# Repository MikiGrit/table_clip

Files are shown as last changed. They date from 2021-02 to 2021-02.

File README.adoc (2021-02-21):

= Modular TableClip System

Do you have table so cluttered you don't see the color of the desk? TableClip to the rescue! ;)

Jokes aside, some time ago I've got inspired by the https://www.thingiverse.com/thing:2892387[USB Cable Organizer] and thought that this could be extended to other useful things and also improved.

So I designed modular system that is divided to parts. The table clip itsef and various modules that can be attached to the clip through lock mechanism.

.Available modules
* cable holder
* pen and paper holder
* headphones holder
* storage box

For the ready-to-print `stl` files, go to https://www.prusaprinters.org/prints/57023-modular-tableclip-system-with-sources[TableClip on prusaprinters.org]

*BUT* the best thing about it is that I'm sharing the sources here. So everybody can design his own modules that can be attached to the base module.

== Designing own modules

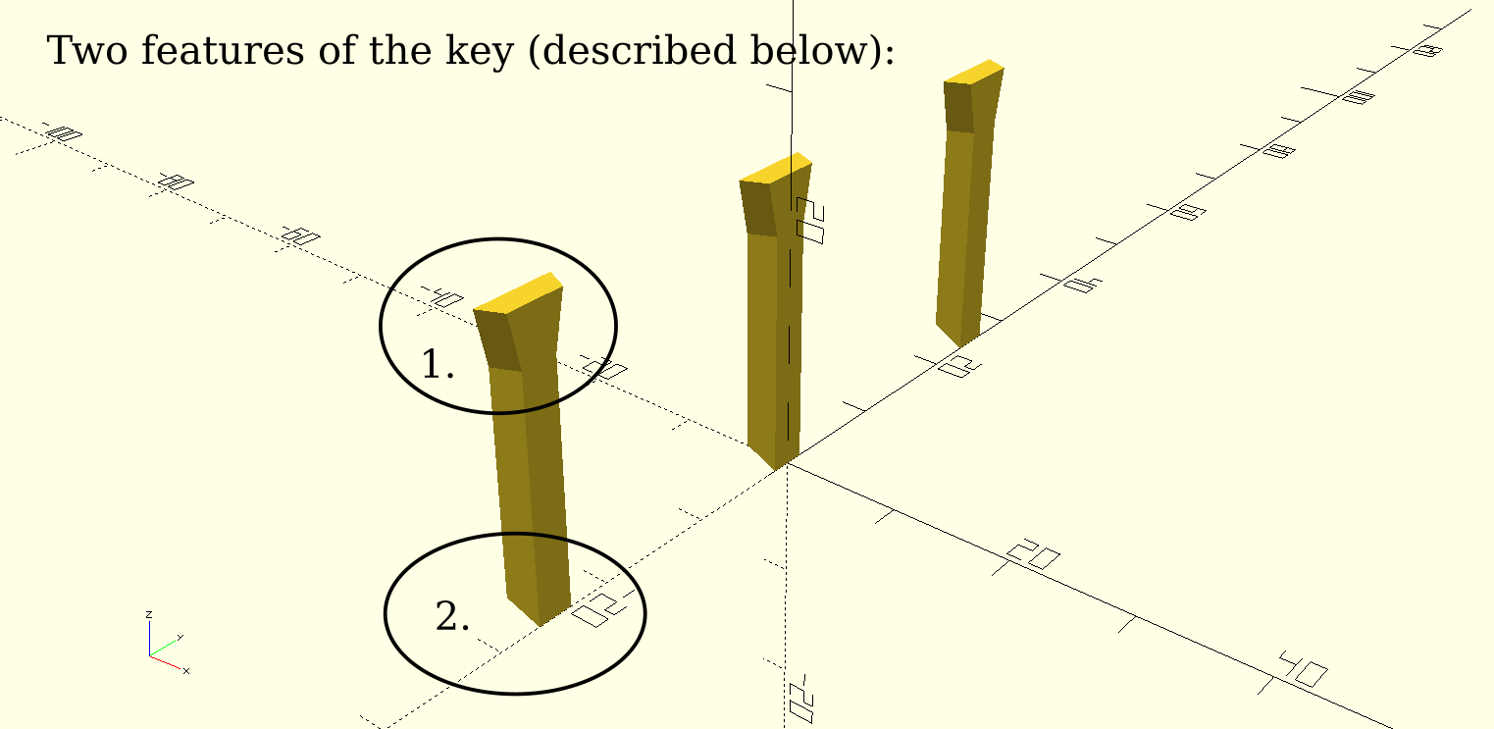
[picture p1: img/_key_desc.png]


If you do not want to design new modules in the OpenSCAD, you can use just the key object (`_key.stl`) and add it to anything you design in program of your choice. The key and the lock themselves are designed in a way that allows two things:

. It is not necessary to print the key in the full height. The connected module still stays on top (see headphones holder for example).
. Key does not have to be printed from the bed, it is fully capable of printing in the middle of the print. The modules themselves can therefore extend below the table (see pencil holder for example).

== Dependencies
* threadlib - https://github.com/adrianschlatter/threadlib
** dependencies of the threadlib (follow the instructions on their page, it's just copying files over)
** scad-utils - https://github.com/openscad/scad-utils
** list-comprehension - https://github.com/openscad/list-comprehension-demos
** thread_profile.scad - https://github.com/MisterHW/IoP-satellite/blob/master/OpenSCAD%20bottle%20threads/thread_profile.scad
* Round-Anything - https://github.com/Irev-Dev/Round-Anything

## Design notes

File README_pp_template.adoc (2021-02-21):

= Model Description

== Print Name

Dell Charger Box for TableClip System

== Summary

Have a power supply that always gets in your way on the table? Clip it from the side!

== Description

Module for the TableClip system: https://www.prusaprinters.org/cs/prints/57023-modular-tableclip-system-with-sources

Does a notebook charger always gets in your way on the table? Clip it from the side!

If you have notebook charger from Dell (and possibly other manufacturers with similar shape), then this box will be perfect for you.

You can also design your own modules with the available sources.

Link to the base module: https://www.prusaprinters.org/cs/prints/57023-modular-tableclip-system-with-sources
Link to the sources: https://github.com/MikiGrit/table_clip

=== Print instructions

Print one base module from the original TableClip print of your choice (`base_*.stl`), two screws and module in this print.

Printable without supports. Tested with 0.2mm layer.

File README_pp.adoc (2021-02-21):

= Model Description

== Print Name

Modular TableClip System (with sources!)

== Summary

Do you have table so cluttered you don't see the color of the desk? TableClip to the rescue!

== Description

Do you have table so cluttered you don't see the color of the desk? *TableClip* to the rescue! ;)

Jokes aside, some time ago I've got inspired by the https://www.thingiverse.com/thing:2892387 and thought that this could be extended to other useful things and also improved.

So I designed modular system that is divided to two parts. The table clip itsef and various modules that can be attached to the clip through lock mechanism.

.Available modules
* cable holder
* pen and paper holder (papers up to 90mm width)
* headphones holder
* storage box (60x100x30mm)

The base modules are currently in 20mm and 30mm width. It is very simple to add additional widths.

*BUT* the best thing about it is that I'm sharing the sources (https://github.com/MikiGrit/table_clip). So everybody can design new modules that can be attached to the base module.

If you do not want to design new modules in the OpenSCAD (for which the sources are), you can use just the key object (`_key.stl`) and add it to anything you design in program of your choice. The key and the lock themselves are designed in a way that allows two things:

. It is not necessary to print the key in full height. The connected module still stays on top (see headphones holder for example).
. Key does not have to be printed from the bed, it is fully capable of printing in the middle of the print. The modules themselves can therefore extend below the table (see pencil holder for example).

Link to the sources: https://github.com/MikiGrit/table_clip

=== Print instructions

For one set, print one base module of your choice (`base_*.stl`), two screws and connecting module with desired functionality.

Everything is printable without supports. Tested with 0.2mm layer.

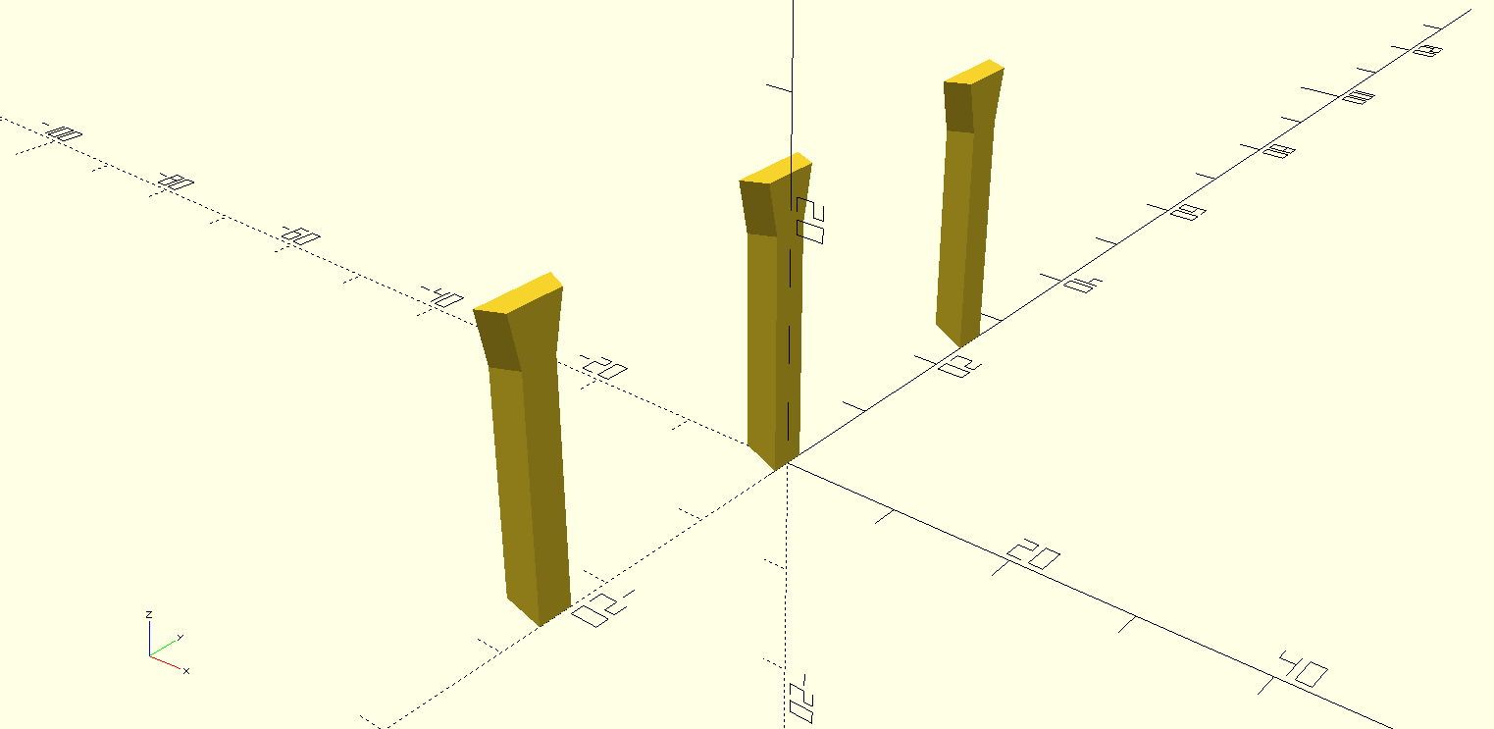
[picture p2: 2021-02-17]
img/_key.png

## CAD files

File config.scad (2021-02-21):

$fa = 6;
$fs = 0.25;

// user defined parameters
default_length = 100;
plane_thickness = 5;
round_corners = true;
screw_length = 8;

//system parameters
tolerance = 0.2;
screw_size = 10;
lock_height = 24;
lock_depth = 2;
lock_width = 6.6;
lock_distance = 25;
lock_pieces = 3;
lock_wall_width = 4;
rounding = 1.5;

// computed parameters
lock_body_height = lock_height - lock_depth;
default_length_true = default_length - 2*rounding;
plane_thickness_true = plane_thickness - 2*rounding;
screw_type = str("M",screw_size);
lock_wall_width_true = lock_wall_width - rounding;

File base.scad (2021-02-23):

use <threadlib/threadlib.scad>

include <config.scad>
use <utils.scad>
use <lock.scad>

table_depth = 20;
table_thickness = 20;
side_thickness = 4;


module handle(lock_pieces = lock_pieces, length = -1) {
    assert(lock_pieces > 0);

    length = length == -1 ? lock_length(pieces=lock_pieces) : length;
    length_true = length - 2*rounding;
    table_depth_true = table_depth;
    side_thickness_true = side_thickness - rounding;

    module skelet() {
        // bottom part
        if (round_corners) {
            translate([side_thickness_true, table_depth_true, 0]) cube([table_depth_true, length_true - 2*table_depth_true, plane_thickness_true]);
            translate([side_thickness_true, length_true - table_depth_true, 0])
              linear_extrude(height=plane_thickness_true)
                intersection() {square(2*(table_depth_true)); circle(r=table_depth_true);}

            translate([side_thickness_true, table_depth_true, 0])
              linear_extrude(height=plane_thickness_true)
               intersection() {translate([0, -2*(table_depth_true), 0]) square(2*(table_depth_true)); circle(r=table_depth_true);}
        } else {
            translate([side_thickness_true, 0, 0]) cube([table_depth_true, length_true, plane_thickness_true]);
        }

        // connecting part
        cube([side_thickness_true, length_true, table_thickness + 2*plane_thickness_true + 2*rounding]);

        // top part
        if (round_corners) {
            translate([side_thickness_true, table_depth_true, plane_thickness_true + table_thickness + 2*rounding]) cube([table_depth_true, length_true - 2*table_depth_true, plane_thickness_true]);
            translate([side_thickness_true, length_true - table_depth_true, plane_thickness_true + table_thickness + 2*rounding])
              linear_extrude(height=plane_thickness_true)
                intersection() {square(2*(table_depth_true)); circle(r=table_depth_true);}

            translate([side_thickness_true, table_depth_true, plane_thickness_true + table_thickness + 2*rounding])
              linear_extrude(height=plane_thickness_true)
               intersection() {translate([0, -2*(table_depth_true), 0]) square(2*(table_depth_true)); circle(r=table_depth_true);}
        } else {
            translate([side_thickness_true, 0, plane_thickness_true + table_thickness + 2*rounding]) cube([table_depth_true, length_true, plane_thickness_true]);
        }
    }

    module screw_taps() {
        if (lock_pieces < 3) {
            translate([0, 0, -1.0]) tap(screw_type, turns=plane_thickness);
        } else {
            tap_distance = lock_distance * ((lock_pieces-1)/2) - 1/5*lock_distance;

            translate([0, tap_distance, -1.0]) tap(screw_type, turns=plane_thickness);
            translate([0, -tap_distance, -1.0]) tap(screw_type, turns=plane_thickness);
        }
    }

    module final() {
        handle_height = 2*plane_thickness + table_thickness + 2*rounding;

        difference() {
            translate([-rounding, 0, 0]) quickMinkowski(rounding) skelet();

            translate([-rounding, 0, 0]) cube([rounding, length, handle_height]);
            #translate([2/3*table_depth, length/2, 0]) screw_taps();
            #translate([0, length/2, 0]) lock(pieces = lock_pieces, height = 2*plane_thickness + table_thickness);
        }
    }

    translate([length, table_thickness + 2*plane_thickness, 0]) rotate([0, -90, 90]) final();
    //final();
}

handle(lock_pieces = 3, length=default_length);

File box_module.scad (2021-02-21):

include <Round-Anything/MinkowskiRound.scad>

include <config.scad>
use <utils.scad>
use <lock.scad>

box_thickness = 4;
box_size = [60, 100, 30];


module box_module(box_size, box_thickness) {

    module shape() {
        minkowskiRound(rounding, rounding, enable=1, boundingEnvelope=2.2*box_size, $fs=1.0) {
            box(box_size, thickness=box_thickness);
        }
    }

    module final() {
        shape();

        translate([0, box_size[1]/2, rounding]) key(height = box_size[2]-2*rounding);
    }

    final();
}

box_module(box_size, box_thickness);

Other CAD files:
cable_module.scad
chamfercyl.scad
charger_box_module.scad
headphones_module.scad
lock.scad
lock_testing.scad
pen_and_paper_module.scad
pencil_module.scad
screw.scad
utils.scad

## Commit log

2021-02-17 Add source files.
    [base.scad, cable_module.scad, chamfercyl.scad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]
2021-02-17 Moving constants.
    [base.scad, cable_module.scad, config.scad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]
2021-02-17 Pencil module added.
    [pencil_module.scad]
2021-02-19 Rewrited pencil_holder.
    [pencil_module.scad, utils.scad]
2021-02-19 Parametrize thickness.
    [pen_and_paper_module.scad]
2021-02-19 Better naming, tweaks.
    [cable_module.scad, config.scad, headphones_module.scad]
2021-02-20 Added storage box.
    [box_module.scad]
2021-02-21 Small code update.
    [box_module.scad, charger_box_module.scad, config.scad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]
2021-02-23 Tuning screw distance.
    [base.scad]
